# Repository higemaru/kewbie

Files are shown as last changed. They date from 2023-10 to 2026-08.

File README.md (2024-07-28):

# Kewbie

'Kewbie' is a series of self-made keyboards by Higemaru.
It means '*KE*yboard made by n*EWBIE* of self-made'.

## Kewbie43 sp
40% splitted keyboard.

kewbie43sp_00

kewbie43sp_01

## Kewbie46

40% keyboard designed for the SONSHI style (placed on top of a MacBook).

kewbie46_00

kewbie46_01

## Kewbie46 LiLi

40% keyboard designed for the SONSHI style (placed on top of a MacBook), and low profile and narrow pitch keys (17mm).

kewbie46_lili

### Build Guide

* [Kewbie46 build guide](kewbie46/guide)

### Bootloader / Customize

* **Physical reset button**: Briefly press the button on the PCB - some may have pads you must short instead
  * To enter USB mass storage mode, press the RESET button with holding down the BOOT button, and write firmware by drag & drop.
* [Firmware](firmware)
  * [Vial](https://vial.today/)
  * [Kewbie46 - Remap](https://remap-keys.app/catalog/hTfNsK0O3Sb1Jaafdm3x)
* [Source code](https://github.com/higemaru/qmk_firmware/)

## Kewbie Keycap

Narrow pitch (17mm) Cherry MX keycaps.

kewbie-keycap
kewbie-keycap-sideview

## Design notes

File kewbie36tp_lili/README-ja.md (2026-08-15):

# Kewbie36tp LiLi

MacBook での尊師スタイル用にデザインした、36キーのキーボードです。

- ロープロファイル狭ピッチ（18 x 17mm） 
  - 。横17.5mm x 縦16.5mm 以下のキーキャップ想定です
- タッチパッドは「動くだけ」レベルです。他の手段がない時の緊急用

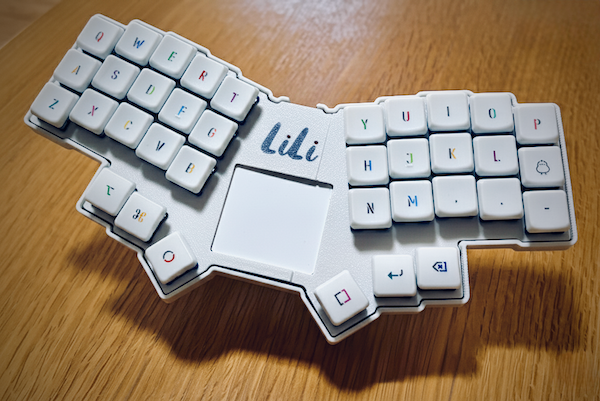
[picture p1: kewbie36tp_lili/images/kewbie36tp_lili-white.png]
kewbie36_00

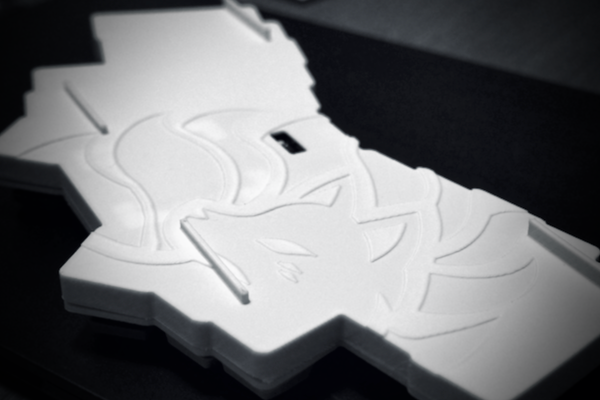
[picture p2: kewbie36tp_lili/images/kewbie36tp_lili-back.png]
kewbie36_00

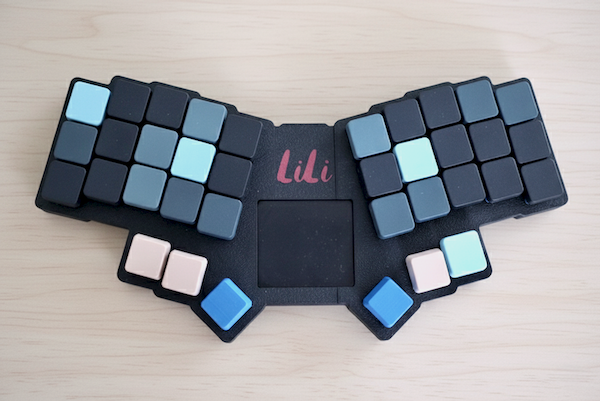
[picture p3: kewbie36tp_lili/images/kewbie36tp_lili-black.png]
kewbie36_01

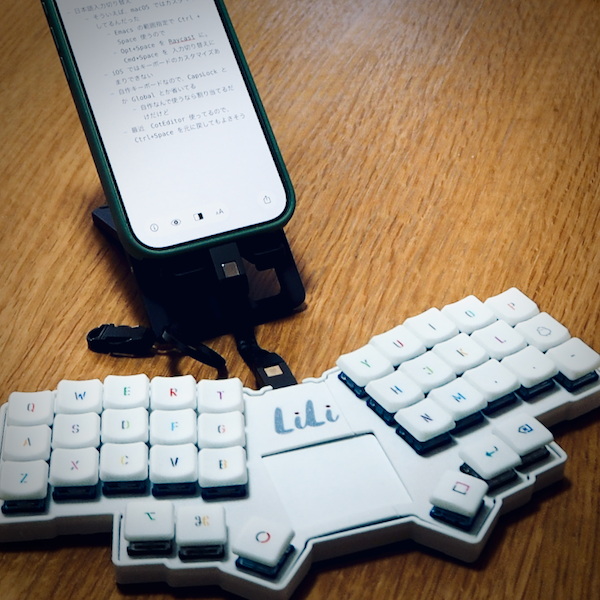
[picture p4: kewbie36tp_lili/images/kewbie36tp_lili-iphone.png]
kewbie36_02


# 必要なパーツ

|Name|Count|Remarks|
|---|--|--|
|PCB|1|1.6mm 厚 [[gerber](gerber/jlcpcb)]|
|トップカバー|1|[[stl](stl/top_cover.stl)]|
|ボトムケース|1|[[stl](stl/bottom_case.stl)]|
|タッチパッド台|1|[[stl](stl/pedestal.stl)]|
|RP2040-Zero|1|https://www.waveshare.com/wiki/RP2040-Zero|
|ダイオード|36|SMD style (SOD123/1N4148W)|
|キーソケット|36| Kailh Choc v1/v2 Compatible|
|キースイッチ|36|Kailh Choc v1/v2 Compatible|
|キーキャップ|36|Kailh Choc v1/v2 Compatible|
|タッチパッド|1|[TPS43-201A-S](https://www.marutsu.co.jp/pc/i/25650684/)|
|FPC コネクター|1|[kinghelm KH-FG0.5-H2.0-6PIN](https://www.lcsc.com/product-detail/C709363.html)|
|リボンケーブル|1|0.5mm 6pin リボンケーブル|
|M2 x 4mm ネジ|12||
|M2 ナット|4||
|M2 x 6mm スペーサー|4||

## ビルドガイド

* [Kewbie36 ビルドガイド](guide)

## ブートローダ / カスタマイズ

* **リセットボタン**: PCB 上のボタンを短く押してください。パッドをショートさせる場合もあります。
  * BOOT ボタンを押しながら RESET ボタンを押すと USB マスストレージモードになり、ドラッグ & ドロップでファームウェアを書き込むことができます

* [Firmware](firmware)
  * [Vial](https://vial.today/)
* [Source code](https://github.com/higemaru/vial-qmk/tree/vial/keyboards/kewbie/kewbie36tp)

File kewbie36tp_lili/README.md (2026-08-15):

# Kewbie36tp LiLi

36Key keyboard designed for the SONSHI style (placed on top of a MacBook).

- Low profile and narrow pitch keys (18 x 17mm).
  -  Designed to use 17.5(w)x16.5(d)mm or smaller keycaps.
- The touchpad is just functional. It's for emergencies.

kewbie36_00
kewbie36_00
kewbie36_01
kewbie36_02

# Required Parts

|Name|Count|Remarks|
|---|--|--|
|PCB|1|1.6mm thick [[gerber](gerber/jlcpcb)]|
|Top Cover|1|[[stl](stl/top_cover.stl)]|
|Bottom Case|1|[[stl](stl/bottom_case.stl)]|
|TouchPad Case|1|[[stl](stl/pedestal.stl)]|
|RP2040-Zero|1|https://www.waveshare.com/wiki/RP2040-Zero|
|Diodes|36|SMD style (SOD123/1N4148W)|
|Key sockets|36| Kailh Choc v1/v2 Compatible|
|Key swtiches|36|Kailh Choc v1/v2 Compatible|
|Keycaps|36|Kailh Choc v1/v2 Compatible|
|Touch Pad|1|[TPS43-201A-S](https://www.marutsu.co.jp/pc/i/25650684/)|
|FPC Connector|1|[kinghelm KH-FG0.5-H2.0-6PIN](https://www.lcsc.com/product-detail/C709363.html)|
|Flat cable|1|0.5mm 6pin ribbon cable|
|Bolt M2 4mm|12||
|Nut M2|4||
|Spacer M2 6mm|4||

## Build Guide

* [Kewbie36 build guide](guide)

## Bootloader / Customize

* **Physical reset button**: Briefly press the button on the PCB - some may have pads you must short instead
  * To enter USB mass storage mode, press the RESET button with holding down the BOOT button, and write firmware by drag & drop.

* [Firmware](firmware)
  * [Vial](https://vial.today/)
* [Source code](https://github.com/higemaru/vial-qmk/tree/vial/keyboards/kewbie/kewbie36tp)

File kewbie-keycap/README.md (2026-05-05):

# Kewbie Keycap

Narrow pitch (17mm) Cherry MX / Choc V2 keycaps.

kewbie-keycap
kewbie-keycap-sideview

## LICENSE

Zero-Clause BSD LICENSE

##   REFERENCES

- [CHERRY MX Developer Information | Individual MX keyboard - Cherry](https://www.cherry-world.com/cherry-mx/developer)
- [tamago324/small-keycaps](https://github.com/tamago324/small-keycaps)
- [bbrfkr/lhs-profile-keycap](https://github.com/bbrfkr/lhs-profile-keycap)
- [OpenSCAD でキーキャップをデザインしてみた - bebebe note](https://bebebe.hatenablog.jp/entry/2019/06/04/232501)
- [キーキャップ設計による OpenSCAD 入門 #自作キーボード - Qiita](https://qiita.com/zk_phi/items/ab99315ebaef66e84aa0)

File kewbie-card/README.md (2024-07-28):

# Kewbie Card

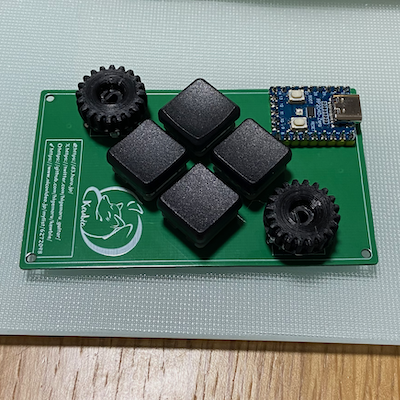
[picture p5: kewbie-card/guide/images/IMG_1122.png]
kewbie_card


# Required Parts

|Name|Count|Remarks|
|---|--|--|
|PCB|1|1.6mm thick|
|RP2040-Zero|1|https://www.waveshare.com/wiki/RP2040-Zero|
|Key swtiches|4|Cherry MX Compatible or Kailh Choc V1|
|Rotaly encoders|2|EC12　Compatible|
|Knob|2|For EC12 Compatible, 6mm D Shaft|

## Build Guide

* [Kewbie Card build guide](guide)

## Bootloader / Customize

* **Physical reset button**: Briefly press the button on the PCB - some may have pads you must short instead
  * To enter USB mass storage mode, press the RESET button with holding down the BOOT button, and write firmware by drag & drop.

* [Firmware](firmware)
  * [Vial](https://vial.today/)
* [Source code](https://github.com/higemaru/qmk_firmware/)

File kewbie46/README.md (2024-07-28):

# Kewbie46

40% keyboard designed for the SONSHI style (placed on top of a MacBook).

kewbie46_00

kewbie46_01

# Required Parts

|Name|Count|Remarks|
|---|--|--|
|PCB|1|1.6mm thick [[gerber](gerber/kewbie46/jlcpcb)]|
|Top plate|1|1.6mm thick [[gerber](gerber/kewbie46/jlcpcb)]|
|Bottom plate|1|1.6mm thick [[gerber](gerber/kewbie46/jlcpcb)]|
|Cover Plate|1|[[gerber](gerber/kewbie46/jlcpcb)]|
|RP2040-Zero|1|https://www.waveshare.com/wiki/RP2040-Zero|
|Diodes|46|SMD style (SOD123/1N4148W)|
|Key sockets|46| Cherry MX Compatible|
|Key swtiches|46|Cherry MX Compatible|
|Keycaps|46|Cherry MX Compatible|
|Spacers M2 5mm|2|
|bolt M2 3mm|4|
|bolt M2 8mm|10|
|Nut M2|20|

## Build Guide

* [Kewbie46 build guide](guide)

## Bootloader / Customize

* **Physical reset button**: Briefly press the button on the PCB - some may have pads you must short instead
  * To enter USB mass storage mode, press the RESET button with holding down the BOOT button, and write firmware by drag & drop.

* [Firmware](firmware)
  * [Vial](https://vial.today/)
  * [Kewbie46 - Remap](https://remap-keys.app/catalog/hTfNsK0O3Sb1Jaafdm3x)
* [Source code](https://github.com/higemaru/qmk_firmware/)

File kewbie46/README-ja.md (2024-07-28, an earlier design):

# Kewbie46

MacBook での尊師スタイル用にデザインした、40% キーボードです。

kewbie46_00

kewbie46_01

# 必要なパーツ

|パーツ|数|説明|
|---|--|--|
|PCB|1|1.6mm 厚 [[gerber](gerber/kewbie46/jlcpcb)]|
|トップレート|1|1.6mm 厚 [[gerber](gerber/kewbie46/jlcpcb)]|
|ボトムプレート|1|1.6mm 厚 [[gerber](gerber/kewbie46/jlcpcb)]|
|MCU カバー|1|[[gerber](gerber/kewbie46/jlcpcb)]|
|RP2040-Zero|1|https://www.waveshare.com/wiki/RP2040-Zero|
|ダイオード|46|SMD style (SOD123/1N4148W)|
|キーソケット|46| Cherry MX Compatible|
|キースイッチ|46|Cherry MX Compatible|
|キーキャップ|46|Cherry MX Compatible|
|スペーサー M2 5mm|2|
|ボルト M2 3mm|4|
|ボルト M2 8mm|10|
|ナット M2|20|

## ビルドガイド

* [Kewbie46 ビルドガイド](guide/README-ja.md)

## ブートローダ / カスタマイズ

* **リセットボタン**: PCB 上のボタンを短く押してください。パッドをショートさせる場合もあります。
  * BOOT ボタンを押しながら RESET ボタンを押すと USB マスストレージモードになり、ドラッグ & ドロップでファームウェアを書き込むことができます
* [Firmware](firmware)
  * [Vial](https://vial.today/)
  * [Kewbie46 - Remap](https://remap-keys.app/catalog/hTfNsK0O3Sb1Jaafdm3x)
* [Source code](https://github.com/higemaru/qmk_firmware/)

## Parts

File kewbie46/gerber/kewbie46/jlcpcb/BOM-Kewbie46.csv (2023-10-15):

Comment | Designator | Footprint | LCSC
~ | D1,D10,D11,D12,D13,D14,D15,D16,D17,D18,D19,D2,D20,D21,D22,D23,D24,D25,D26,D27,D28,D29,D3,D30,D31,D32,D33,D34,D35,D36,D37,D38,D39,D4,D40,D41,D42,D43,D44,D45,D46,D5,D6,D7,D8,D9 | D_SOD-123 | C81598

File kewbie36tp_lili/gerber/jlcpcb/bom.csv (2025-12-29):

Designator | Footprint | Quantity | Value | LCSC Part #
D10, D12, D13, D14, D15, D16, D17, D18, D19, D20, D21, D22, D23, D24, D25, D26, D27, D28, D29, D30, D31, D32, D33, D34, D35, D36, D37, D38, D40, D41, D42, D5, D6, D7, D8, D9 | D_SOD-123 | 36 | 1N4148W | C81598
FPC1 | FPC-SMD_KH-FG0.5-H2.0-6PIN | 1 | ~ | C709363
SW11, SW12, SW13, SW14, SW15, SW16, SW17, SW18, SW19, SW20, SW21, SW22, SW23, SW24, SW25, SW26, SW27, SW28, SW29, SW30, SW31, SW32, SW33, SW34, SW35, SW36, SW37, SW39, SW40, SW43, SW44, SW5, SW6, SW7, SW8, SW9 | ChocV1_V2_Hotswap_0_9u_with_vias | 36 | SW_Push | C3305516

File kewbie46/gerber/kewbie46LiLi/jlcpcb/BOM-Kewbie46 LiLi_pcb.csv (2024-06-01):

Comment | Designator | Footprint | LCSC
SW_Push | SW1,SW10,SW11,SW12,SW13,SW14,SW15,SW16,SW17,SW18,SW19,SW2,SW20,SW21,SW22,SW23,SW24,SW25,SW26,SW27,SW28,SW29,SW3,SW30,SW31,SW32,SW33,SW34,SW35,SW36,SW37,SW38,SW39,SW4,SW40,SW41,SW42,SW43,SW44,SW45,SW46,SW5,SW6,SW7,SW8,SW9 | ChocV1_V2_Hotswap_0.9u | C5333465
D | D1,D10,D11,D12,D13,D14,D15,D16,D17,D18,D19,D2,D20,D21,D22,D23,D24,D25,D26,D27,D28,D29,D3,D30,D31,D32,D33,D34,D35,D36,D37,D38,D39,D4,D40,D41,D42,D43,D44,D45,D46,D5,D6,D7,D8,D9 | D_SOD-123 | C81598

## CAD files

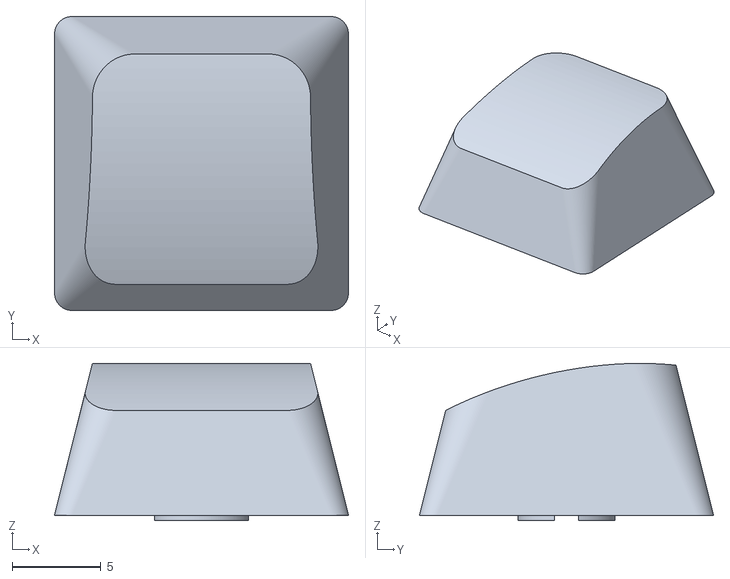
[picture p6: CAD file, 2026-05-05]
kewbie-keycap/stl/convex_3dp.stl
16.6 x 16.6 x 8.88

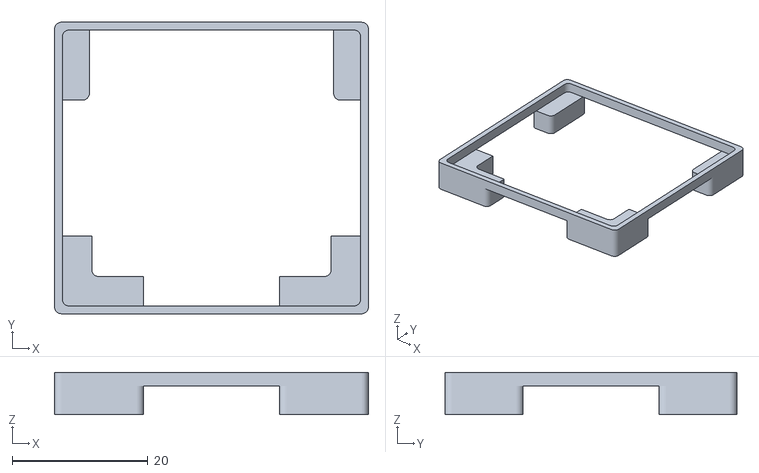
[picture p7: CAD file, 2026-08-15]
kewbie36tp_lili/stl/pedestal.stl
46.3 x 43.0 x 6.20

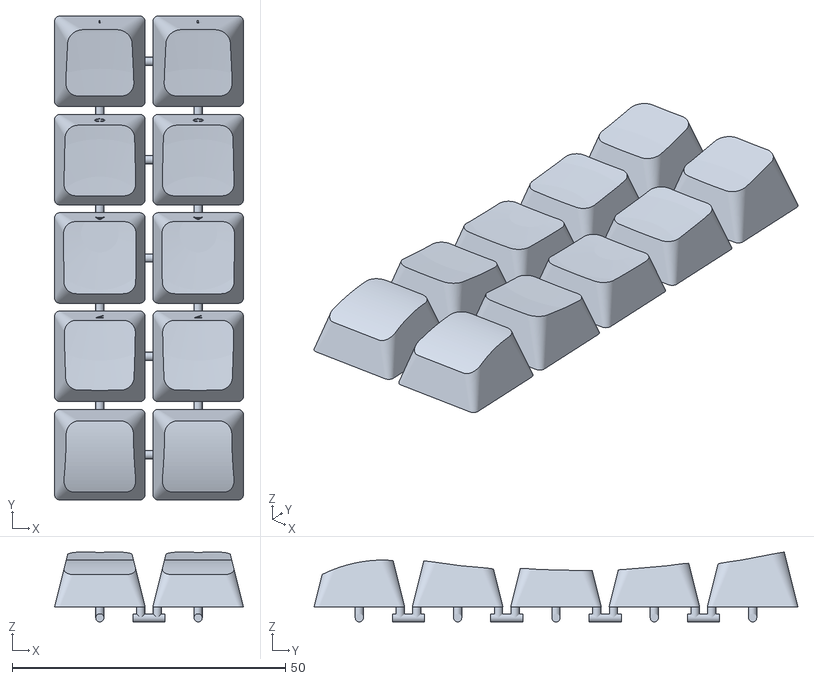
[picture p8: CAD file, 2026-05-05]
kewbie-keycap/stl/sample_jlc3dp.stl
34.6 x 88.6 x 12.8

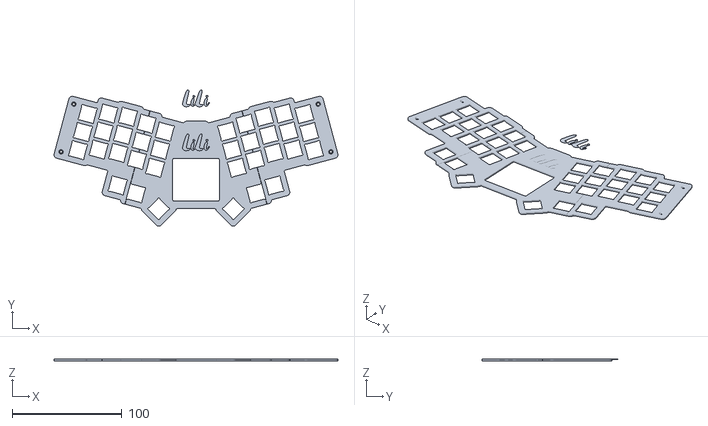
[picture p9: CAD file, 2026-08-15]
kewbie36tp_lili/stl/top.stl
258.2 x 124.0 x 1.40

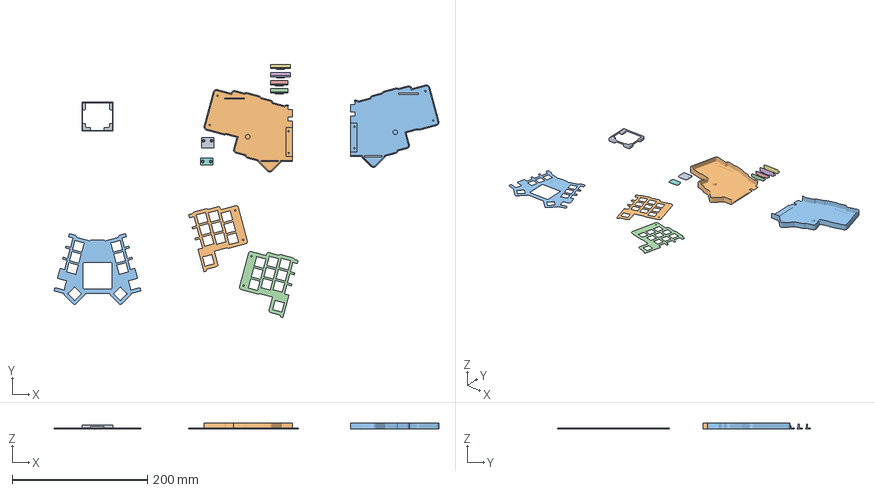
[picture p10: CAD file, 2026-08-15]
kewbie36tp_lili/stl/kewbie36tp-lili.3mf
569.9 x 375.2 x 9.31 mm
pedestal.stl
bottom.stl_1
bottom.stl_2
bottom.stl_3
bottom.stl_4
bottom.stl_5
bottom.stl_6
bottom.stl_7
bottom.stl_8
top.stl_1
top.stl_2
top.stl_3
top.stl_4
top.stl_5
top.stl_6
top.stl_7
top.stl_8

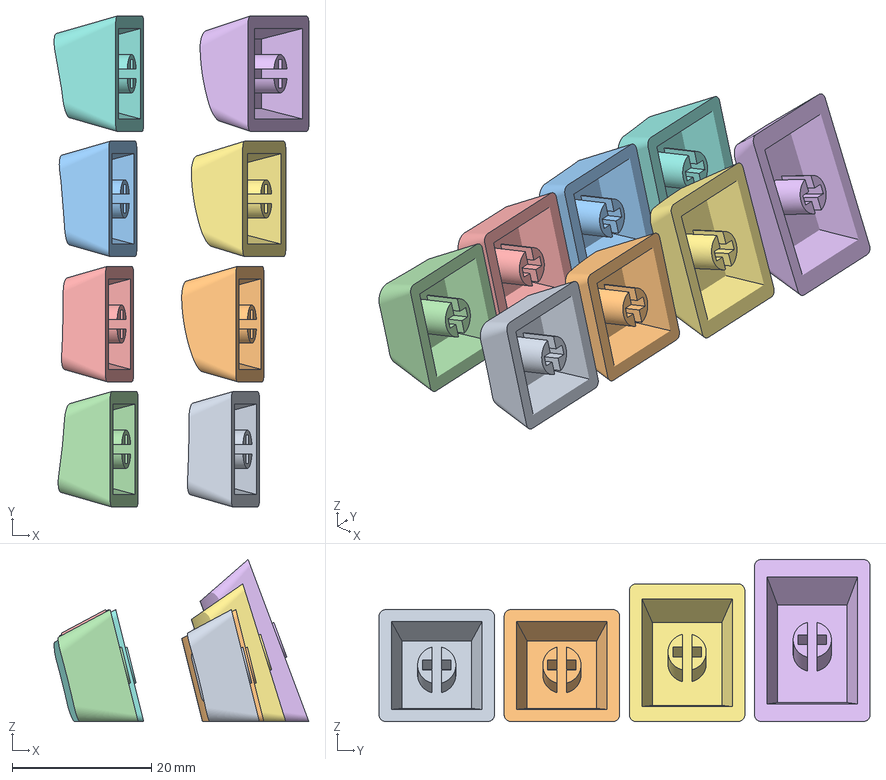
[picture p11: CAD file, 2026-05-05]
kewbie-keycap/stl/kewbie-keycap_bs.3mf
36.6 x 70.6 x 23.3 mm
kewbie-keycap.stl_1
kewbie-keycap.stl_2
kewbie-keycap.stl_4
kewbie-keycap.stl_5
kewbie-keycap.stl_6
kewbie-keycap.stl_7
kewbie-keycap.stl_8
kewbie-keycap.stl_3

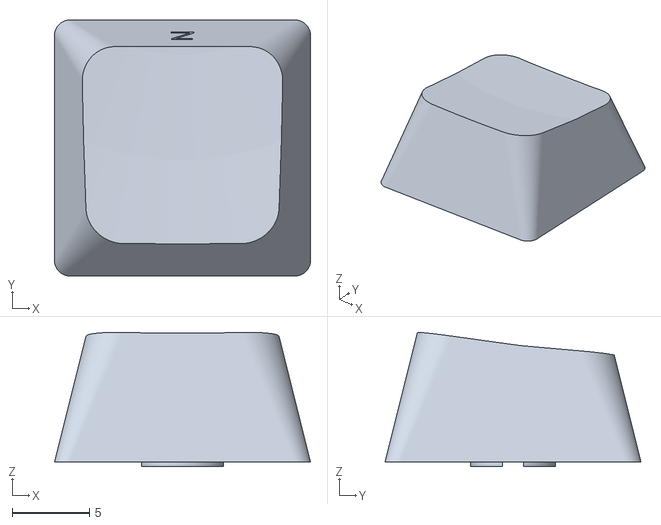
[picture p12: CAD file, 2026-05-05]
kewbie-keycap/stl/r4_3dp.stl
16.6 x 16.6 x 8.71

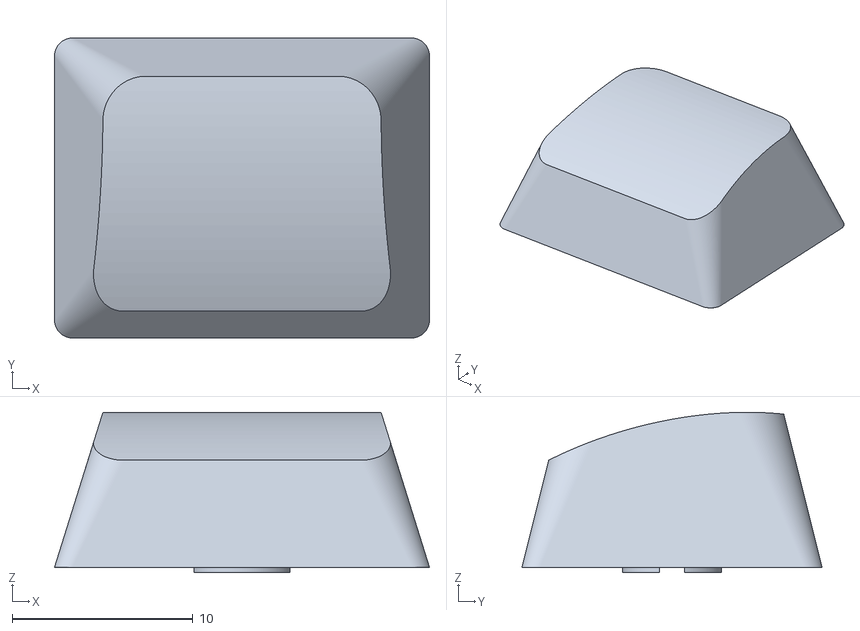
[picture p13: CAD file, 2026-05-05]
kewbie-keycap/stl/convex_125_3dp.stl
20.8 x 16.6 x 8.88

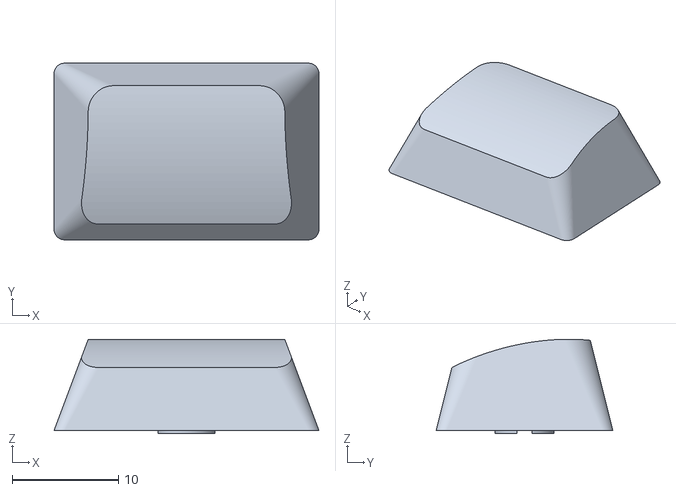
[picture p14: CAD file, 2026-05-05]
kewbie-keycap/stl/convex_150_3dp.stl
24.9 x 16.6 x 8.88

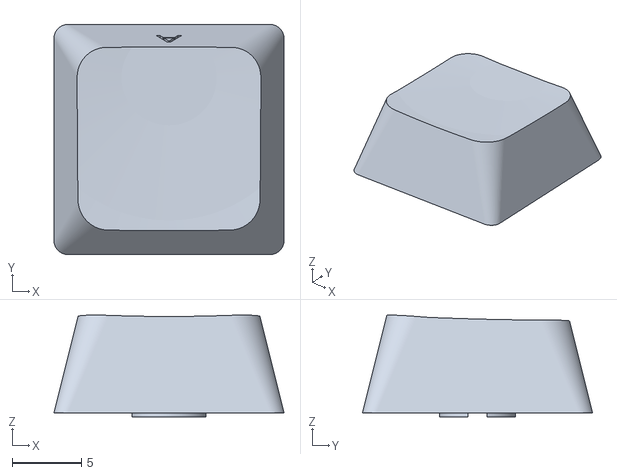
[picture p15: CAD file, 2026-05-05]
kewbie-keycap/stl/r3_3dp.stl
16.6 x 16.6 x 7.35

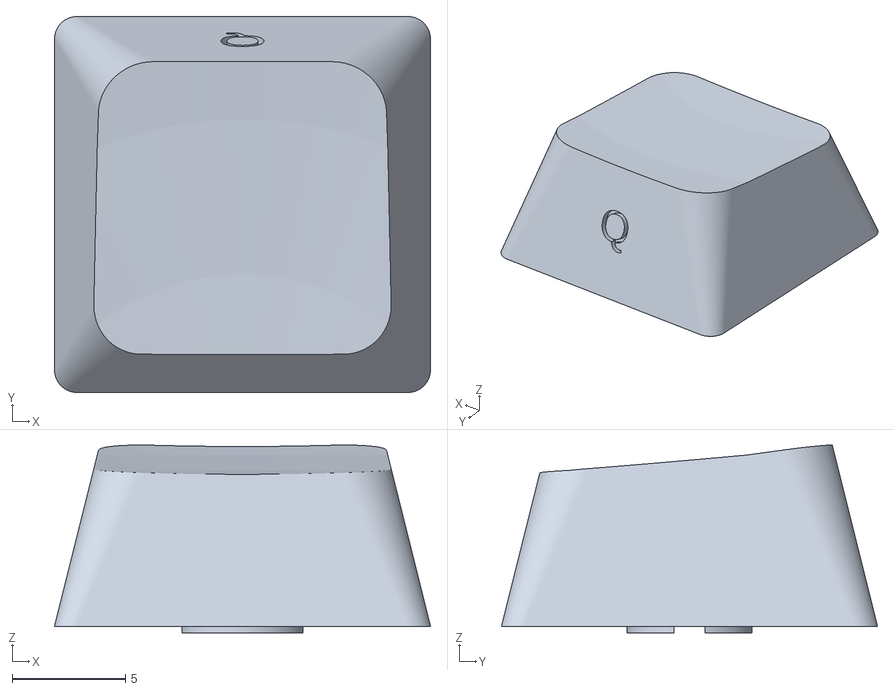
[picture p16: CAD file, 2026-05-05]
kewbie-keycap/stl/r2_3dp.stl
16.6 x 16.6 x 8.30

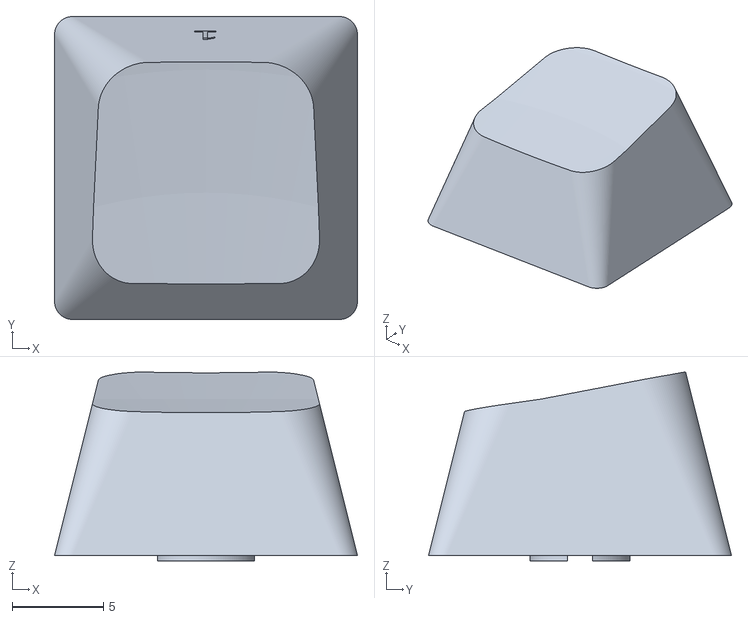
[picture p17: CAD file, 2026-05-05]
kewbie-keycap/stl/r1_3dp.stl
16.6 x 16.6 x 10.3

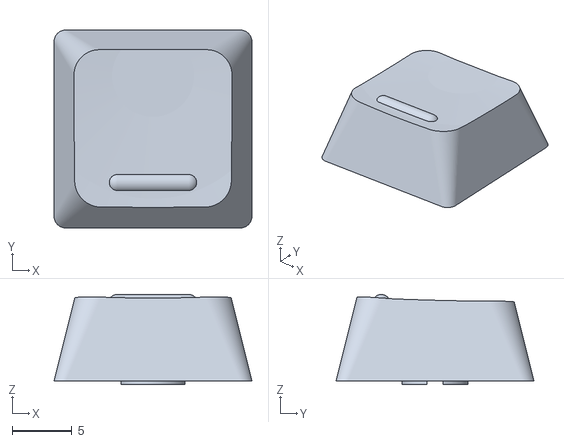
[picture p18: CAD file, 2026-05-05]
kewbie-keycap/stl/home_3dp.stl
16.6 x 16.6 x 7.55

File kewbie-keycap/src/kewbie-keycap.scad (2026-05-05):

/*
  kewbie-keycap.scad
  Narrow-pitch / Original profile keycap

  Copyright (C) 2025 by KAWABATA, Kazumichi
  SPDX-License-Identifier: 0BSD

  Permission to use, copy, modify, and/or distribute this software for any
  purpose with or without fee is hereby granted.

  THE SOFTWARE IS PROVIDED "AS IS" AND THE AUTHOR DISCLAIMS ALL WARRANTIES
  WITH REGARD TO THIS SOFTWARE INCLUDING ALL IMPLIED WARRANTIES OF
  MERCHANTABILITY AND FITNESS. IN NO EVENT SHALL THE AUTHOR BE LIABLE FOR
  ANY SPECIAL, DIRECT, INDIRECT, OR CONSEQUENTIAL DAMAGES OR ANY DAMAGES
  WHATSOEVER RESULTING FROM LOSS OF USE, DATA OR PROFITS, WHETHER IN AN
  ACTION OF CONTRACT, NEGLIGENCE OR OTHER TORTIOUS ACTION, ARISING OUT OF
  OR IN CONNECTION WITH THE USE OR PERFORMANCE OF THIS SOFTWARE.

  references:
    https://www.cherrymx.de/en/dev.html
    https://github.com/tamago324/small-keycaps
    https://github.com/bbrfkr/lhs-profile-keycap
    https://bebebe.hatenablog.jp/entry/2019/06/04/232501
    https://qiita.com/zk_phi/items/ab99315ebaef66e84aa0
*/

$fn = 128;

// =========================================
// Customizer
// =========================================

/* [Output] */
target = "home"; // [jlc3dp, home]

/* [1u Keys] */
num_R1          = 0; // [0:20]
num_R2          = 0; // [0:20]
num_R3          = 1; // [0:20]
num_R4          = 0; // [0:20]
num_Home        = 0; // [0:20]
num_Convex      = 0; // [0:20]
num_Convex_Home = 0; // [0:20]

/* [Wide Keys] */
num_Convex_125u = 0; // [0:20]
num_Convex_150u = 0; // [0:20]

/* [Layout] */
cols = 2; // [1:5]

/* [Hidden] */

// ステム関連（Cherry MX 互換）
stem_diameter    = 5.5;   // ステムの直径
stem_cross_wide  = 4.1;   // ステムの十字の幅（広い方）
stem_cross_narrow= 1.17;  // ステムの十字の幅（狭い方）
stem_height      = 14;    // ステムの高さ
stem_shift       = 0;     // 底面から内に引っ込める長さ

// キャップ関連
// ※ 一部の数値は実測と試作による微調整の結果
pitch      = 17;          // 狭ピッチ
wall_thick = 1.8;         // キャップ側面の厚さ

cap_top_inner    = 10;
cap_top_outer    = 7 + wall_thick * 2;  // 天面は inner より小さめに調整
cap_bottom_inner = 13;
cap_bottom_outer = cap_bottom_inner + wall_thick * 2;

cap_height_outer = 12;
cap_height_inner = cap_height_outer - wall_thick - 4.8; // 内部空間の深さ調整

rad          = 140;       // キートップ曲面を削り取る球の半径
cap_interval = 18;        // キーキャップを並べる時のピッチ
fontsize     = 2;         // 浮き彫り文字のサイズ

// ランナー関連（jlc3dp 発注時にキャップ間をつなぐサポート構造）
runner_h = 2;             // ランナーの足の高さ
runner_d = 1.5;           // ランナーの直径
cap_gap  = cap_interval - cap_bottom_outer; // 並べた時の隙間

// FDM 印刷補正（自宅3Dプリンター用）
// ステム十字溝を広げてキースイッチにはまるようにする。要実測調整。
fdm_clearance  = 0.2;
fdm_stem_shift = -0.3;   // ステムを底面から引っ込める

// =========================================
// ステム
// =========================================

// Cherry MX 互換の十字ステム
// $fdm_clearance が設定されている場合、十字溝を広げる
module _my_stem() {
    cl = is_undef($fdm_clearance) ? 0 : $fdm_clearance;
    difference() {
        translate([0, 0, stem_height / 2])
            cylinder(r = stem_diameter / 2, h = stem_height, center = true);
        // 十字の縦棒
        translate([0, 0, stem_height / 2])
            cube([stem_cross_narrow + cl, stem_cross_wide, stem_height], center = true);
        // 十字の横棒。貫通させて上下に少し開くようにする
        translate([0, 0, stem_height / 2])
            cube([stem_diameter, stem_cross_narrow - 0.1 + cl, stem_height], center = true);
    }
}

// =========================================
// キャップ形状
// =========================================

// 角丸直方体
module _my_rounded_cube(size, r) {
    h = 0.0001;
    minkowski() {
        cube([size[0] - r * 2, size[1] - r * 2, size[2] - h], center = true);
        cylinder(r = r, h = h);
    }
}

// 角丸直方体を積み重ねてキーキャップの形にする
module _my_cap_shape(top, bottom, height, unit=1, rounded=true) {
    hull() {
        if (rounded) {
            translate([0, 0, height])
                _my_rounded_cube([top * unit, top, 0.01], 3);
            _my_rounded_cube([bottom * unit, bottom, 0.01], 1);
        }
        else {
            translate([0, 0, height])
                cube([top * unit, top, 0.01], center = true);
            cube([bottom * unit, bottom, 0.01], center = true);
        }
    }
}

// キーキャップ外形
module _my_cap_outer(unit=1, rounded=true) {
    _my_cap_shape(cap_top_outer, cap_bottom_outer, cap_height_outer, unit, rounded);
}

// キーキャップ内形
module _my_cap_inner(unit=1, rounded=false) {
    _my_cap_shape(cap_top_inner, cap_bottom_inner, cap_height_inner, unit, rounded);
}

// 凸キャップ用の形状（親指キー等に使用）
// 各数値は実測による微調整
module _convex(unit=1) {
    rotate([0, 90, 0]) {
        rotate([0, 0, 15]) scale([1, 1.8, 1])
            cylinder(pitch * unit, 8, 8, true);
    }
}

// 一つのキーキャップ（行プロファイル付き）
// row の値で球面カットの Y 位置が変わり、行ごとの傾斜を表現する
// row: R1=1.9, R2=2.3, R3=2.9, R4=3.3（実測による微調整値）
module _my_cap(row=3, char="", unit=1, depth=0) {
    ss = is_undef($stem_shift) ? stem_shift : $stem_shift;
    difference() {
        union() {
            translate([0, 0, ss])
                _my_stem();
            difference() {
                _my_cap_outer(unit = unit);
                _my_cap_inner(unit = unit);
            }
        }
        // キーキャップの内側に文字を浮き彫り
        if (char != "") {
            theta = atan(cap_height_outer / ((cap_bottom_outer - cap_top_outer) / 2));
            translate([0, (cap_bottom_outer - wall_thick) / 2 - depth, ss + fontsize * 2]) {
                rotate([theta, 0, 180]) {
                    linear_extrude(wall_thick) {
                        text(
                            text = char,
                            size = fontsize,
                            halign = "center",
                            valign = "center"
                        );
                    }
                }
            }
        }
        // 球面カットで行プロファイルの傾斜をつける
        translate([0, pitch * 1.75 * (row - 2.75), rad + 6.5])
            sphere(r = rad);
    }
}

// =========================================
// ランナー
// =========================================

// キャップ間をつなぐランナー1本分（縦棒2本＋横棒1本）
module _runner(gap=cap_gap) {
    // キーキャップとつながる縦棒
    translate([-(gap + runner_d / 2 + wall_thick / 2) / 2, 0, -(runner_h) / 2])
        cylinder(r = runner_d / 2, h = runner_h, center = true);
    translate([ (gap + runner_d / 2 + wall_thick / 2) / 2, 0, -(runner_h) / 2])
        cylinder(r = runner_d / 2, h = runner_h, center = true);
    // 縦棒同士をつなぐ横棒
    translate([0, 0, -runner_h])
        rotate([0, 90, 0])
            cylinder(r = runner_d / 2, h = gap + runner_d * 3, center = true);
}

// x列 × y行 のキャップ間をランナーでつなぐ
// x_interval: 列間の距離（ワイドキー用に変更可能）
module runners(x=1, y=1, x_interval=cap_interval, x_gap=cap_gap) {
    // 横方向（列間）
    for (x = [1:x-1]) {
        for (y = [0:y-1]) {
            translate([x_interval * x - x_interval / 2, cap_interval * y, 0])
                _runner(x_gap);
        }
    }
    // 縦方向（行間）
    for (x = [0:x-1]) {
        for (y = [0:y-2]) {
            translate([x_interval * x, cap_interval * y + cap_interval / 2, 0])
                rotate([0, 0, 90]) _runner();
        }
    }
}

// =========================================
// キャップ単体
// =========================================

module cap_r1() {
    _my_cap(1.9, "1", depth = 0.5);
}
module cap_r2() {
    _my_cap(2.3, "Q", depth = 0.5);
}
module cap_r3() {
    _my_cap(2.9, "A", depth = 0.5);
}
module cap_r4() {
    _my_cap(3.3, "Z", depth = 0.5);
}

// ホームポジション用のバンプ（突起）
// 各数値は実測による微調整
module _home_bump() {
    hull() {
        translate([-3, -4.5, 6.5]) sphere(0.75);
        translate([ 3, -4.5, 6.5]) sphere(0.75);
    }
}

module cap_home() {
    _my_cap(2.9, "");
    _home_bump();
}

module cap_convex(unit=1) {
    ss = is_undef($stem_shift) ? stem_shift : $stem_shift;
    union() {
        intersection() {
            translate([0, 0, ss])
                _my_stem();
            _convex(unit = unit);
        }
        intersection() {
            difference() {
                _my_cap_outer(unit = unit);
                _my_cap_inner(unit = unit);
            }
            _convex(unit = unit);
        }
    }
}

module cap_convex_home(unit=1) {
    cap_convex(unit);
    _home_bump();
}

// =========================================
// 出力用ひとまとめ
// =========================================

// 同一行キャップ 2×5=10個セット
module rx10(row, char) {
    for (x = [0:1]) {
        for (y = [0:4]) {
            translate([x * cap_interval, y * cap_interval, 0])
                _my_cap(row, char, depth = 0.5);
        }
    }
    runners(2, 5);
}

// 同一行キャップ10個 + y==0 をホームキーに差し替え
module rx10_home(row, char) {
    for (x = [0:1]) {
        for (y = [0:4]) {
            translate([x * cap_interval, y * cap_interval, 0])
                if (y == 0) cap_home();
                else _my_cap(row, char, depth = 0.5);
        }
    }
    runners(2, 5);
}
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

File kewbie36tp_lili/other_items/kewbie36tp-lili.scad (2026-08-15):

//include <BOSL2/std.scad>

//$fn = 128;
$fs=0.1;

// top logo 40mm 下げる

cs = 17;  // キャップのサイズ
cs_w=18;
cs_orig=19;
//cs = 17.5;  // キャップのサイズ
//cs = 19;  // キャップのサイズ
//hs = 14;  // スイッチ穴のサイズ
hs = 14.1;  // スイッチ穴のサイズ。3Dプリンタの時は少し大きめに
ps = 1.6; // PCB の厚さ
cb = 1.4; // Choc はかま深さ
ms = 2.667; // 縦ずれ
case_depth=8.5;

// 3Dプリントしたケース組み立て用のクリアランス
// Bambu PLA Matte だと、 top / ottom 0.5 でちょっと強度不足。マステで隙間調整がよさそう
// bottom 0.3 だときつめで少し反る。0.4 だと反らないけどやや浮く
slop=0.5;

/*
 * KLE 由来。微調整でなんとなく決まった数字
 * ソースコード中にも、手調整したマジックナンバーが 3 年分積もってて見通し悪い
 */
y_base_offset=4.141;   // Y方向基準オフセット値
y_compensation=18.624; // Y方向オフセットの補正値

xshift = -cs*6-cs/2;
yshift = -y_base_offset+y_compensation;
xrshift = -cos(30)*cs*cos(45);
yrshift = sin(30)*cs*sin(45);

xwshift = 10.5;  // 真ん中のスペース / 2
   echo("xshift:",xshift);

// ===== 追加パラメータ =====
// 天板の外形クリアランス（片側 mm）。この値をそのまま「片側の隙間」として読める。
//   壁の内面 : offset(1 + slop*2)
//   天板の外形: offset(2 - slop_fit)
//   slop=0.5 のとき 壁 2.0 / 天板 2-slop_fit なので、隙間 = slop_fit そのもの。
// slop に寄せると 隙間 = 3*slop-1 となり slop の変化が 3 倍で効く。
// 意図が読めなくなるので独立の値として持つ。
//
// 0.15 では 259mm の印刷物に対して詰めすぎで、分割印刷の誤差を吸収できず
// 天板がギチギチだったため 0.4 に広げた。
// 使用箇所は top_cover() の 1 行のみ。外形だけが縮み、
// キー穴・ネジ穴・TPS43 穴は動かない。
slop_fit    = 0.4;   /// 天板外形クリアランス 片側mm（旧: ラビット継手クリアランス 0.15）

// 最内列（左半分の T / 右半分の Y）を中央から離す量 mm。左右それぞれに効く。
// OpenSCAD で SVG 出力 -> KiCad にインポート -> アタリにして手配置、という
// 経路のため、PCB 側の左右グループ間隔が SCAD より僅かに広い。
// 天板の中央ピースを嵌めるとき左右に引っ張る形になっていたので、
// 天板側の最内列を外へ逃がして吸収する。
//   0.1 で左右合計 0.2mm 広がる。T-R 列間ピッチは 18 -> 17.9（0.5%、体感不可）
//   15 度回転後の水平成分は 0.1*cos15 = 0.097mm。補正不要
//   ウイングは main2 列（Y=0 で X=61.79）以降なので影響を受けない
// キー配置は lefthalf() の 1 箇所だけ。右半分は mirror なので自動的に対称。
inner_col_adj = 0.1;


// セルフタッピング用ボスパラメータ
boss_od    = 7;
screw_pass = 2.3;    // bottom 側の通し穴径
csink_d    = 4.2;    // 皿ザグリ径
csink_h    = 1.3;    // 皿ザグリ深さ


lug        = 8;    // 左右張り出し量（boss_od 5.5 + 余裕）
lug_margin = 4;    // ボス中心から lug 端までの余裕

// 支柱の位置（穴と穴の中央）
support_pos = [
//    [cs_w*6.25, y_base_offset-ms+cs*2.5],   // Q-W間、中段
    [cs_w*4, y_base_offset-1],   // E-R間、中段
];
   
module keyswitch(switch=true,hole=true) {
    w=cs_orig;
    h=cs_orig;
    hh=hs;
    circle_shift=0.71;
    circle_dia=2;

    difference() {
        if ( switch )
            square([w,h]);
        if ( hole ) {
            cx = (w-hh)/2;
            cy = (h-hh)/2;
            translate([cx,cy,0]) square(hh);
            translate([cx+circle_shift,cy+circle_shift,0]) circle(d=circle_dia);
            translate([cx+circle_shift,cy+hh-circle_shift,0]) circle(d=circle_dia);
            translate([cx+hh-circle_shift,cy+circle_shift,0]) circle(d=circle_dia);
            translate([cx+hh-circle_shift,cy+hh-circle_shift,0]) circle(d=circle_dia);
        }
    }
}
module keyswitch_column(switch=true,hole=true) {
    for( y = [0 : 2]) {
        translate([0,cs*y,0]) keyswitch(switch,hole);
//        translate([0,(cs+1)*y,0]) keyswitch(switch,hole,w,h);
    }
}
module shiftbasepos(w=cs,h=cs){
    translate([-xrshift-h*cos(60)-w*cos(30), -yrshift+w*sin(30)-h*sin(60), 0])
        children();
}
// z 起点
module position_from_z_key(w=cs,h=cs) {
    shiftbasepos(w,h)
        translate([xshift, yshift, 0])
            children();
}
// t 起点。6列の時に作ったので、5列だと t の横ではないが、穴埋め用なので気にしない
module position_from_t_key(w=cs,h=cs) {
    position_from_z_key(w,h)
        translate([cs*6, y_base_offset+cs*2, 0])
            children();
}
// opt 起点
module position_from_thumb_left(w=cs, h=cs) {
    translate([cs*2+9.144, y_base_offset+ms-w, 0])
        position_from_z_key(w,h)
            children();
}

// キー配置
module lefthalf(switch=true,hole=true,lug=0) {
    w=cs_orig;
    h=cs_orig;

    shiftbasepos(w,h) {
        translate([xshift-5, yshift, 0]) {
            translate([cs_w  , y_base_offset-ms,     0]) keyswitch_column(switch,hole); // Q
            translate([cs_w*2, y_base_offset+ms,       0]) keyswitch_column(switch,hole); // W
            translate([cs_w*3, y_base_offset+ms+1.714, 0]) keyswitch_column(switch,hole); // E
            translate([cs_w*4, y_base_offset+ms,       0]) keyswitch_column(switch,hole); // R
            translate([cs_w*5 - inner_col_adj, y_base_offset, 0]) keyswitch_column(switch,hole); // T
            translate([cs*2+9.144, y_base_offset+ms-w-5-0.25, 0]) {
                translate([cs_w, -ms, 0]) keyswitch(switch,hole); // opt
                translate([cs_w*2, -ms*2, 0]) keyswitch(switch,hole); // cmd
            }
            // Q列左端から外側に張り出し
            if (lug > 0)
                translate([cs_w - lug, y_base_offset-ms, 0])
                    square([lug, cs*3+h-cs]);
            }
echo(cs*2+9.144);
        // mod
//         translate([xrshift, yrshift-5*cos(15)-0.5, 0])
         translate([xrshift, yrshift-5*cos(15)-0.5-1, 0])
            rotate([0, 0, -30])
//                translate([0,-cs*0.4,0])
                translate([0,-cs*0.4-4-1,0])
                    keyswitch(switch,hole);

    }
}

module lefthalf_for_base(lug=0) {
    margin = 1; // 外周マージン
    w=cs_orig;
    h=cs_orig;

    offset(delta=margin){ // 外周広げる
        //mod 付近埋める
        translate([13*cos(60),7*sin(60),0]) rotate([0,0,150]) square([19.5,43.75]);
        //cmd 付近埋める
        translate([cs*2, -ms*2, 0]) position_from_thumb_left(w,h) square([w*2,h]);

        //英数付近埋める
        position_from_thumb_left(-3,h) square([w*3,h*1.5]);
        position_from_thumb_left(w,h) translate([-w,h*0.79]) square([w*2,h]);
        //
        // 英数の横埋めたければここかな
        //

        // T列より内側埋める
        translate([0, -28.5, 0])
            position_from_t_key(w,h)
                square([19,47.5]);

        //大枠
        lefthalf(switch=true,hole=false,lug=lug);
    }
}

module roundedcorner(r=2) {
    offset(r=-r/2)offset(delta= r/2)
    offset(r=-r/2)offset(delta= r/2)
    offset(r= r/2)offset(delta=-r/2)
    offset(r= r/2)offset(delta=-r/2)
        children();
}


module base_plate(lug=0){
    centermargin = 65; // 中央の空間を埋める
    spacewidth = 24+(xwshift-4)*2;

    roundedcorner(3) {
        // 上をたいらに
        translate([-10,66.8-7.2,0]) square([20,4]);

        // 中央の空きをうめる
        translate([-spacewidth/2,-8-4.8,0]) square([spacewidth,centermargin]);

        translate([-xwshift,0,0])
            rotate([0,0,-15])
                lefthalf_for_base(lug=lug);
        translate([xwshift,0,0])
            rotate([0,0,15])
                mirror([1,0,0]) lefthalf_for_base(lug=lug);

    }
}

module bottom_case(lug=0) {
    usbport_w=12;
    rim_h = 1.0;
    difference() {
        union(){
            // 壁
echo("case_depth:",case_depth);
echo("cb:",cb);
//            linear_extrude(case_depth-cb)
            linear_extrude(case_depth)
                difference() {
                    offset(2.6+slop*2) base_plate(lug=lug);
                    offset(1+slop*2) base_plate(lug=lug);
//                    offset(0.5+slop*2) base_plate(lug=lug);
                    translate([-usbport_w/2,66.-case_depth,0])
                        square([usbport_w,27]);
                }
            // 床
            linear_extrude(cb)
                offset(2) base_plate(lug=lug);

            //角丸
            translate([0,0,case_depth]) {
                r=(2.6-1)/2;
                n=8;
                dz = r/n;
                for (i = [0 : n-1]) {
                    a = asin(i/n);          // z = r*sin(a) = i*dz と一致
                    translate([0, 0, i*dz])
                        linear_extrude(dz + 0.01)
                            difference() {
                                offset(2.6+slop*2 - r + r*cos(a)) base_plate(lug=lug);
                                offset(1+slop*2 + r - r*cos(a)) base_plate(lug=lug);
                                translate([-usbport_w/2, 66.-case_depth, 0])
                                    square([usbport_w, 27]);
                            }
                }
            }
                
            // ラビット継手レッジ
/*            translate([0,0,case_depth-cb])
                linear_extrude(cb)
                    difference() {
                        offset(2+slop*2) base_plate(lug=lug);
                        offset(1+slop*2) base_plate(lug=lug);
//                        offset(2+slop_fit) base_plate(lug=lug);
                        translate([-usbport_w/2,66.-case_depth,0])
                            square([usbport_w,27]);
                    }
*/
            // ネジボス（lug 位置、床から立ち上がる）
/*            if (lug > 0)
                place_all_lug_bosses(lug)
                    boss_with_nut(case_depth-cb);*/

            // 支柱（たわみ防止）
            place_all_support_pillars()
                cylinder(d=boss_od, h=case_depth-cb-ps-0.2, $fn=32);
                // case_depth-cb-ps = 8.5-1.4-1.6 = 5.5mm
                    
                    
        }
        // リセットボタン用の穴
        translate([-7,43.5,0])
            linear_extrude(1.5)
                roundedcorner() square([14, 6]);
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

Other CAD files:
kewbie36tp_lili/other_items/pcb.dxf
kewbie36tp_lili/other_items/top_cover.dxf
kewbie-keycap/stl/convex_home_3dp.stl
kewbie-keycap/stl/kewbie-keycap.3mf

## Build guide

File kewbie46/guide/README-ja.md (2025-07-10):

# ビルドガイド

Kewbie46 ビルドガイドです

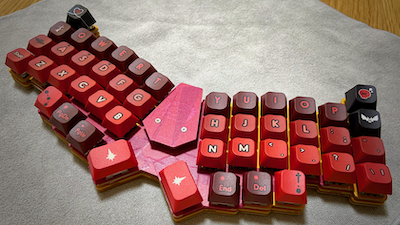
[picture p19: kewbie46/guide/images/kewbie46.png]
kewbie46


## 必要なパーツ

|パーツ|数|説明|
|---|--|--|
|PCB|1|1.6mm 厚 [[gerber](../gerber/kewbie46/jlcpcb)]|
|トップレート|1|1.6mm 厚 [[gerber](../gerber/kewbie46/jlcpcb)]|
|ボトムプレート|1|1.6mm 厚 [[gerber](../gerber/kewbie46/jlcpcb)]|
|MCU カバー|1|[[gerber](../gerber/kewbie46/jlcpcb)]|
|RP2040-Zero|1|https://www.waveshare.com/wiki/RP2040-Zero|
|ダイオード|46|SMD style (SOD123/1N4148W)|
|キーソケット|46| Cherry MX Compatible|
|キースイッチ|46|Cherry MX Compatible|
|キーキャップ|46|Cherry MX Compatible|
|スペーサー M2 5mm|2|
|ボルト M2 3mm|4|
|ボルト M2 8mm|10|
|ナット M2|20|

## 組み立て

### 始めに

他のキーボード作者さんが、丁寧なビルドガイドを作成されています。読むだけで学びになりますので、いくつか事前に読まれることをお勧めします。

### MCU動作チェック

Kewbie46 は「RP2040-Zero」というマイコンを使っています。はんだづけをする前に、まず、ファームウェアを書き込んで、不良品でないことを確認します。

1. USB ケーブルで PC に接続する
   - USB マスストレージとしてマウントされます
   - マウントされない場合は、接続した状態で、RP2040-Zero 上の「BOOT」を押しながら「RESET」を押してみてください
2. ファームウェアを書き込む
   - [ファームウェアをダウンロード](../firmware/)し、1. でマウントされた USB メディアにドラッグ & ドロップします
3. キーボードとして認識されているかどうか確かめます
   1. ウェブブラウザ [Google Chrome](https://www.google.com/intl/ja_jp/chrome/) で、[Vial のウェブサイト](https://get.vial.today/)にアクセスします
     - WebHID 対応ブラウザでアクセスする必要があります
   2. 「Start Vial Web」をクリック→「Start Vial」をクリック
   3. HIDデバイスへの接続ダイアログが表示されるので「Kewbie46」を選択して接続
   4. デフォルトのキーマップが表示されたら成功です

### ボトムプレート

羽根の部分を除去してヤスリで磨いたら完成です

- 手で折れると思います
- 折りとった部分を隙間に刺すことで、チルト用の足として利用可能です
  - MacBook のキーボードの行幅に合わせているので、MacBook のキーボードの上にそのままのせることができます
  - チルト不要なら、四隅にゴム足をつける、全面にゴムシートを貼る等でも
    - 全面ゴムシートでも、MacBook のキーボードに置くことは可能です。MacBook 自体を傾けないなら、その方が気軽です
    - MacBook を傾ける場合は、チルト用の足がフックになって、ある程度までは傾けても大丈夫だと思います

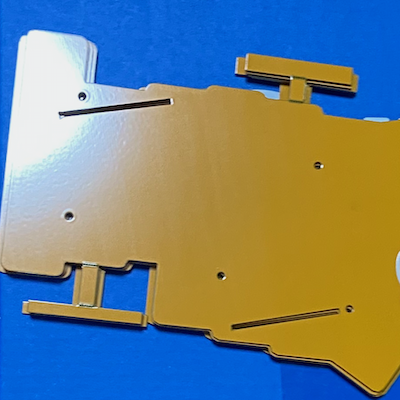
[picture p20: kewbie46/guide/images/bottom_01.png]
bottom_01

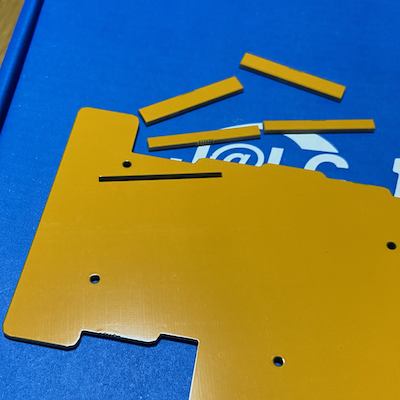
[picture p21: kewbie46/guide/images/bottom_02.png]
bottom_02

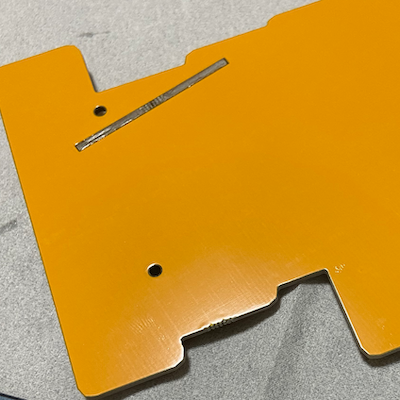
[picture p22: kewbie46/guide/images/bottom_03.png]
bottom_03

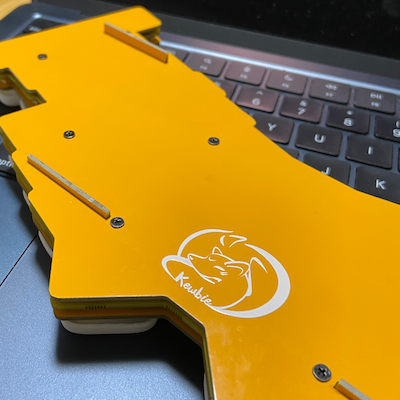
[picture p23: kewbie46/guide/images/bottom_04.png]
bottom_04


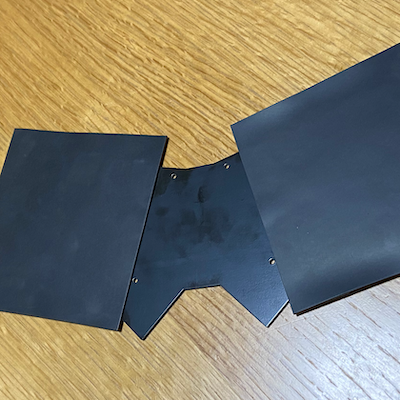
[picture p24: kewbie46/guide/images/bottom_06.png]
bottom_06


### PCB

#### ダイオード

ダイオードははんだ付け済みです

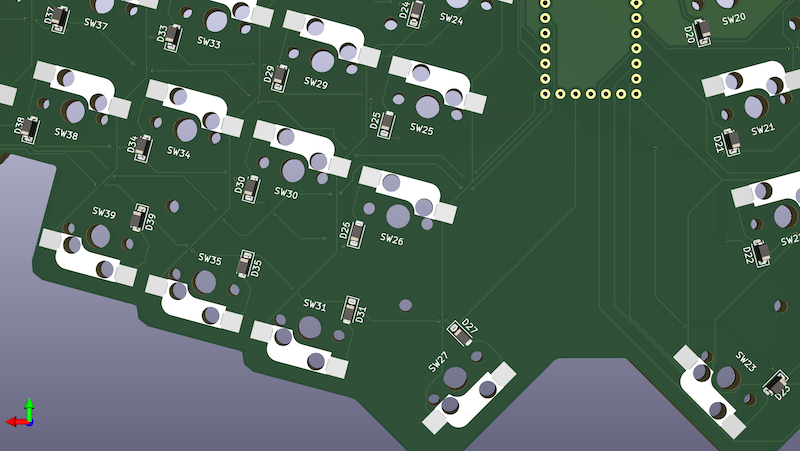
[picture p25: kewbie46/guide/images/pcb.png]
diode_01


#### キーソケット

はんだ付けのコツは、いろんなサイトで紹介されているので事前に見てみてください。大まかには

1. 片側にハンダを盛って置く
2. 盛ったハンダを熱しつつ、ピンセットではさんだキーソケットを軽く押し当てる
3. ハンダゴテを離せば固定されている
4. もう片方もハンダ付けして完了

です。そんなに神経質にならなくても大丈夫です。

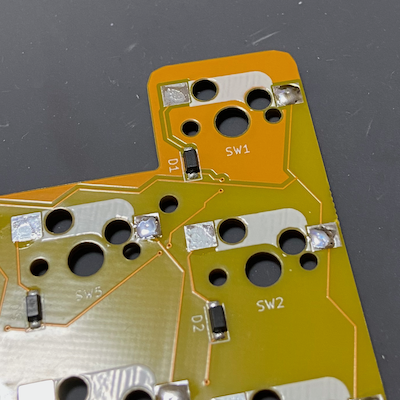
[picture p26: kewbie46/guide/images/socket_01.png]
socket_01

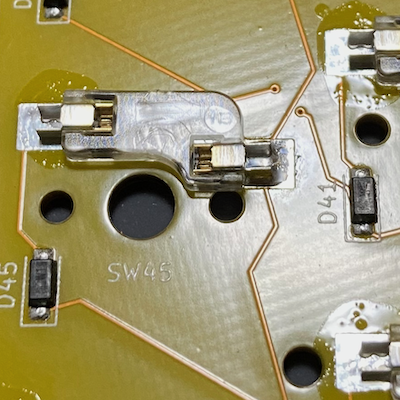
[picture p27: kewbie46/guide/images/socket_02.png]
socket_02


#### MCU

マスキングテープで固定して作業するとやりやすくなります。私はカプトンテープ（絶縁耐熱）を使い回してます。

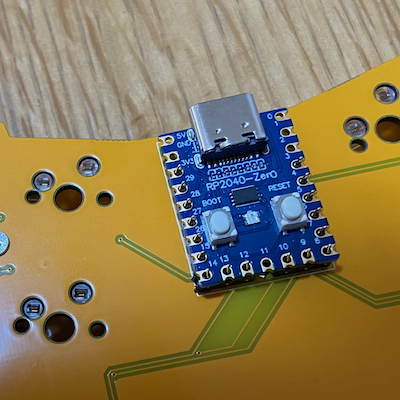
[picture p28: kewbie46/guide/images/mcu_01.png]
mcu_01


以下、写真は違うキーボードのものです。

ピンを並べて、その上に RP2040-Zero をのせ、マスキングテープで固定してはんだづけ

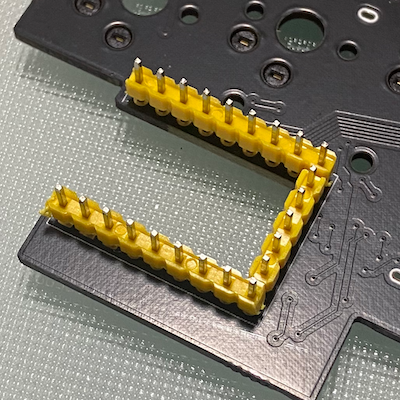
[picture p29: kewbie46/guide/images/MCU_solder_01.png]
MCU_solder_01
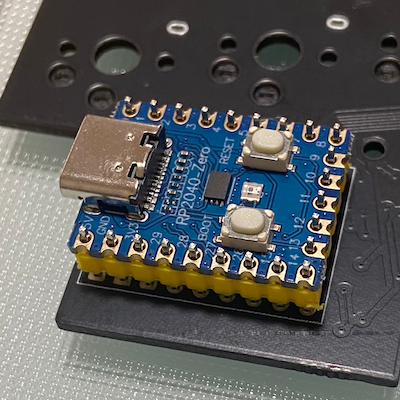
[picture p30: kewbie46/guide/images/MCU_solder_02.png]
MCU_solder_02
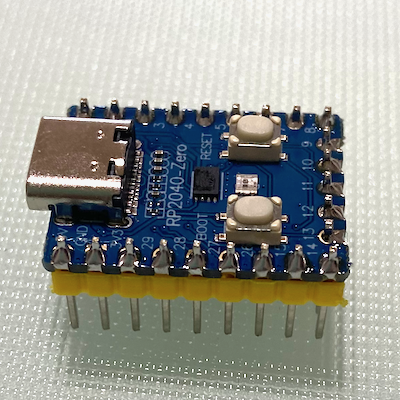
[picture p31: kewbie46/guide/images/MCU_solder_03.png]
MCU_solder_03


表が終わったら裏側もハンダづけ。マスキングテープで傾きがないように固定し直してください。私はピンを先に切ってから作業するほうがやりやすいです

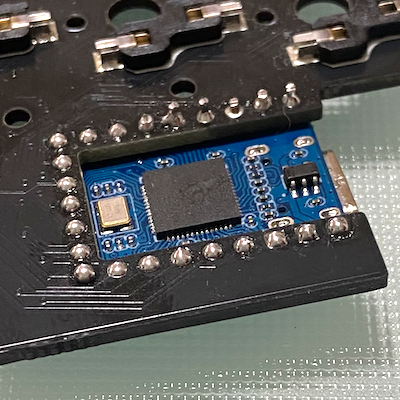
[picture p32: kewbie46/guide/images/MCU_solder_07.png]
MCU_solder_07


### PCB & ボトムプレート

ボトムプレートの外側から 8mm ネジを通し、ナットで固定します

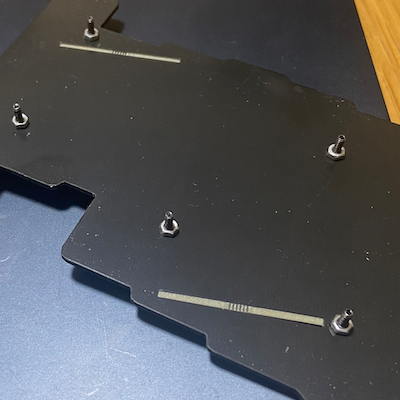
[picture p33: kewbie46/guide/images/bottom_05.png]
bottom_05


ボトムプレートに固定されたネジを、PCB のネジ穴に通し、ナットで固定してください

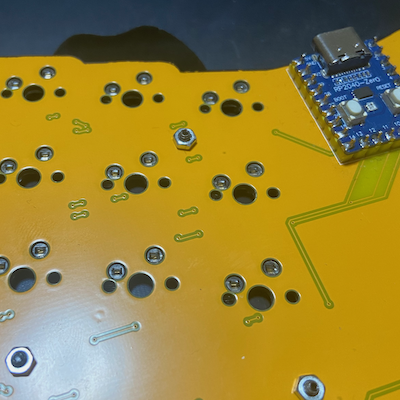
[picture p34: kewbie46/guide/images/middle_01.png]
middle_01


※ナットが他パーツに接触してショートすることがあるようです。その場合は、カプトンテープ等で絶縁してください

### トップレート

トッププレートはかぶせているだけです。

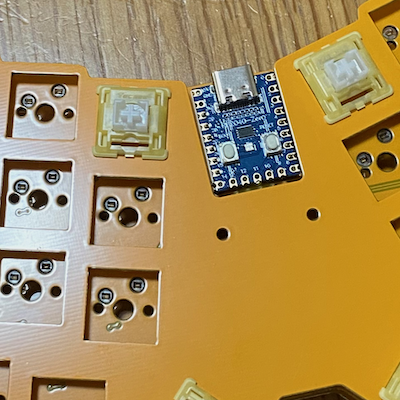
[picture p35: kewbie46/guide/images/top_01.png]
top_01


### その他

#### 塗装

基板の側面に着色すると、全体が絞まって見えます。黒なら「マッキー」「ポスカ」等お好きなもので。黒以外は、いくつか試しましたが、下記が塗りやすくて好みです。

- TOMSING アクリルマーカーペン
- GSIクレオス ガンダムマーカーEX

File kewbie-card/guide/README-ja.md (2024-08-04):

# ビルドガイド

Kewbie Card のビルドガイドです

## 必要なパーツ

|パーツ|数|説明|
|---|--|--|
|PCB|1|1.6mm 厚|
|RP2040-Zero|1|https://www.waveshare.com/wiki/RP2040-Zero|
|Key swtiches|4|Cherry MX Compatible or Kailh Choc V1|
|Rotaly encoders|2|EC12　Compatible|
|Knob|2|For EC12 Compatible, 6mm D Shaft|

## 始めに

他のキーボード作者さんが、丁寧なビルドガイドを作成されています。読むだけで学びになりますので、いくつか事前に読まれることをお勧めします。

## MCU動作チェック

「RP2040-Zero」というマイコンを使っています。はんだづけをする前に、まず、ファームウェアを書き込んで、不良品でないことを確認します。

1. USB ケーブルで PC に接続する

   - USB マスストレージとしてマウントされます
   - マウントされない場合は、接続した状態で、RP2040-Zero 上の「BOOT」を押しながら「RESET」を押してみてください

2. ファームウェアを書き込む

   - [ファームウェアをダウンロード](../firmware/)し、1. でマウントされた USB メディアにドラッグ & ドロップします

3. キーボードとして認識されているかどうか確かめます

   1. ウェブブラウザ [Google Chrome](https://www.google.com/intl/ja_jp/chrome/) で、[Vial のウェブサイト](https://get.vial.today/)にアクセスします

     - WebHID 対応ブラウザでアクセスする必要があります

   2. 「Start Vial Web」をクリック→「Start Vial」をクリック
   3. HIDデバイスへの接続ダイアログが表示されるので「Kewbie」を選択して接続
   4. デフォルトのキーマップが表示されたら成功です

## 組み立て

### 始めに

すべてのパーツです。古い基板だと、エンコーダ用のノブは、直径の大きいものはキーボードと干渉して回りません。

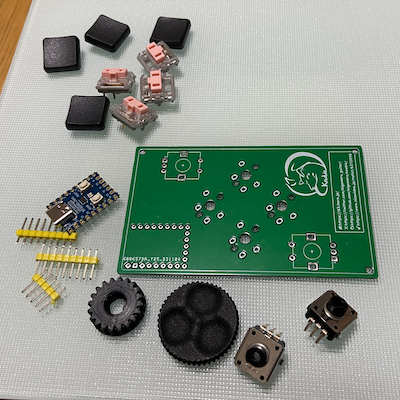
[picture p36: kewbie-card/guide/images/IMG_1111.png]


Cherry MX もしくは Choc V1/V2 のキースイッチを並べて、裏側からはんだ付けしてください。マスキングテープで固定して作業するとやりやすくなります。私はカプトンテープ（絶縁耐熱）を使っています。キースイッチが傾かないよう注意してください。

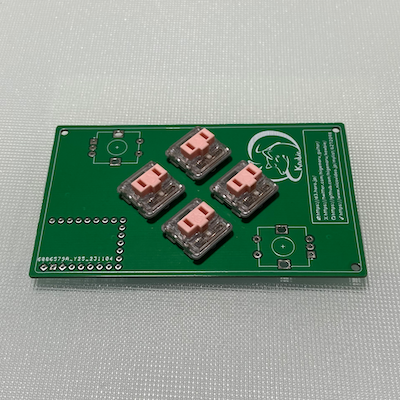
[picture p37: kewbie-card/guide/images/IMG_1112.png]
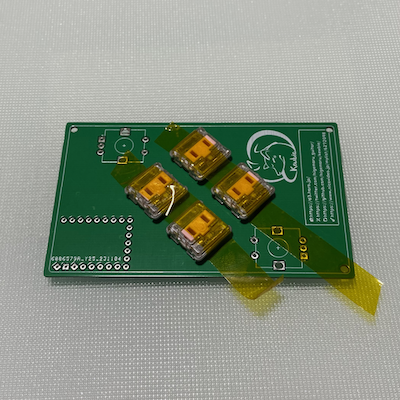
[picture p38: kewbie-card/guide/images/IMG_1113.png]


他のパーツも同様に。

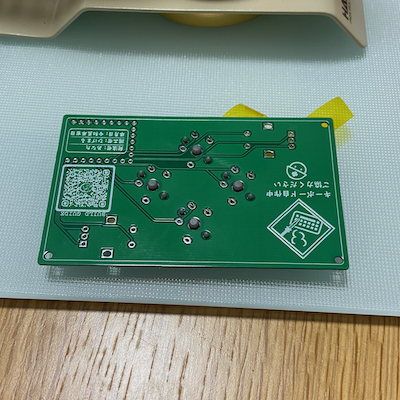
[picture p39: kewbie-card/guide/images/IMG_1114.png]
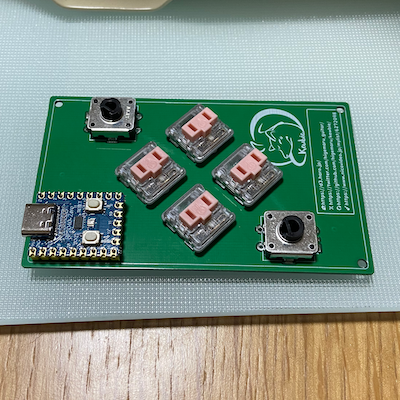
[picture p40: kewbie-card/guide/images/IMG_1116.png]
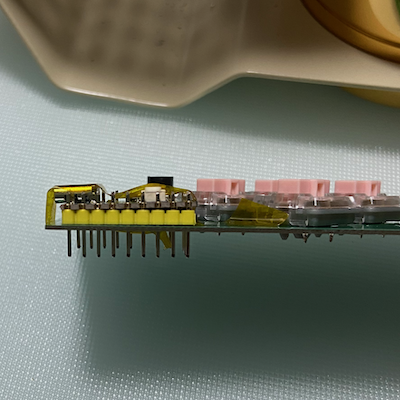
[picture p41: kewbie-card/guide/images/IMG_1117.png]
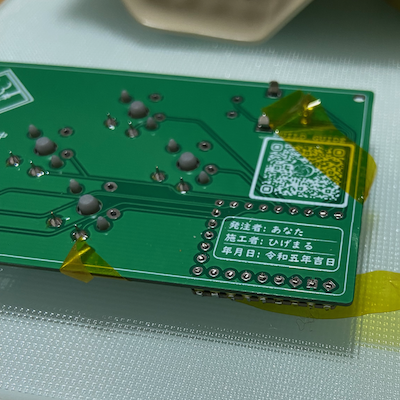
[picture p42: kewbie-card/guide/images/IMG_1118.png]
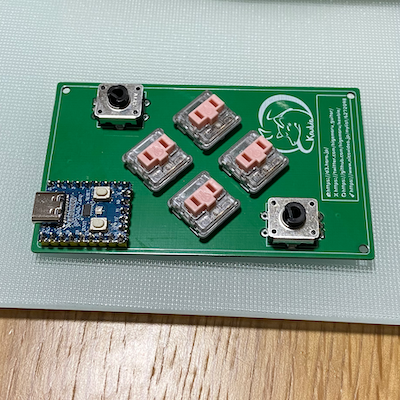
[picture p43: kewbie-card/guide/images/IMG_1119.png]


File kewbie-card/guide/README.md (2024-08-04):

# Build Guide

This is the building guide for Kewbie Card.

## Required Parts

|Name|Count|Remarks|
|---|--|--|
|PCB|1|1.6mm thick|
|RP2040-Zero|1|https://www.waveshare.com/wiki/RP2040-Zero|
|Key swtiches|4|Cherry MX Compatible or Kailh Choc V1|
|Rotaly encoders|2|EC12　Compatible|
|Knob|2|For EC12 Compatible, 6mm D Shaft|

## Introduction

Other keyboard authors have provided great build guides. I recommend that you read some of them beforehand, so you will learn a lot .

## Check the MCU

"Kewbie" uses a microcontroller "RP2040-Zero". Before soldering, first you should write the firmware to make sure it is not defective.

## Assembly

On older boards, the knobs for encoders with larger diameters will not turn (because they interfere with the keyboard).



Line up the Cherry MX or Choc V1/V2 key switches and solder from the back side.
It is easier to work with masking tape to hold it in place.I use Kapton tape (insulation heat resistant).
Be careful not to tilt the key switch.



same for other parts.



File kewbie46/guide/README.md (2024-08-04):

# Build Guide

This is the building guide for Kewbie46.

kewbie46

## Required Parts

|Name|Count|Remarks|
|---|--|--|
|PCB|1|1.6mm thick [[gerber](../gerber/kewbie46/jlcpcb)]|
|Top plate|1|1.6mm thick [[gerber](../gerber/kewbie46/jlcpcb)]|
|Bottom plate|1|1.6mm thick [[gerber](../gerber/kewbie46/jlcpcb)]|
|Cover Plate|1|[[gerber](../gerber/kewbie46/jlcpcb)]|
|RP2040-Zero|1|https://www.waveshare.com/wiki/RP2040-Zero|
|Diodes|46|SMD style (SOD123/1N4148W)|
|Key sockets|46| Cherry MX Compatible|
|Key swtiches|46|Cherry MX Compatible|
|Keycaps|46|Cherry MX Compatible|
|Spacers M2 5mm|2|
|bolt M2 3mm|4|
|bolt M2 8mm|10|
|Nut M2|20|

## Assembly

### Introduction

Other keyboard authors have provided great build guides. I recommend that you read some of them beforehand, so you will learn a lot .

### Check the MCU

"Kewbie46" uses a microcontroller "RP2040-Zero". Before soldering, first you should write the firmware to make sure it is not defective.

### Bottom Plate

bottom_01
bottom_02
bottom_03
bottom_04

bottom_06

### PCB

#### Diode

Diode is already soldered.

diode_01

#### Key sockets

socket_01
socket_02

#### MCU

mcu_01

MCU_solder_01MCU_solder_02MCU_solder_03

MCU_solder_07

### PCB & Bottom

bottom_05
middle_01

### Top Plate

top_01

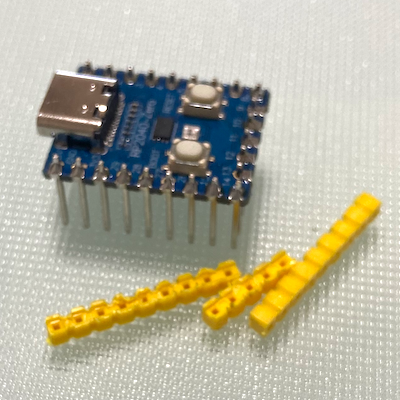
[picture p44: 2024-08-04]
kewbie46/guide/images/MCU_solder_05.png

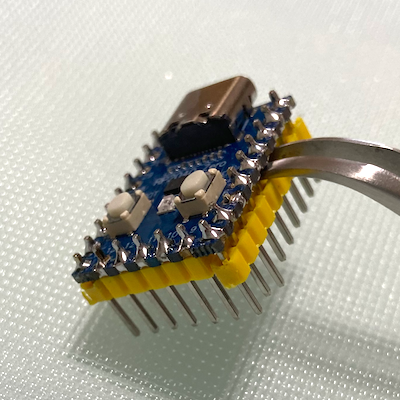
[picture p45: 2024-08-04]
kewbie46/guide/images/MCU_solder_04.png

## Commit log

2023-10-18 fix gerber link
2024-03-10 init kewbie-keycap
    [cap_convex.stl, cap_convex_1_25.stl, cap_convex_1_50.stl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]
2024-06-01 add kewbie46lili
    [BOM-Kewbie46 LiLi_pcb.csv, BOM-Kewbie46.csv, other_keys.stl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]
2024-07-24 s/thick/厚/
2025-12-29 add kewbie36tp_lili
    [bom.csv, positions.csv]
2026-05-05 set default value (for MakerWorld)
    [kewbie-keycap.scad]
2026-08-15 add items
    [kewbie36tp-lili.3mf, kewbie36tp-lili.scad, pcb.dxf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]
2026-08-15 add bot/nut/spacer on README
